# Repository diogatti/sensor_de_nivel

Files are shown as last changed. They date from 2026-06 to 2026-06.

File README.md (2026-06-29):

Este trabalho apresenta uma solução simples e de baixo custo para monitoramento e controle automático do nível de água em um reservatório para aplicações de curto prazo. Visando reduzir desperdícios e promover praticidade e eficiência, foi desenvolvido um sensor resistivo e, de acordo com a medição, exibe-se o valor em um display LCD e controla-se uma bomba de água para regular o volume, utilizando uma Raspberry PI como microcontrolador. Para garantir a precisão, realizou-se a calibração com base em valores conhecidos, o tratamento dos dados na lógica de programação e projetou-se uma estrutura que pudesse ser acoplada ao recipiente para melhorar a estabilidade. O sistema apresentou bons resultados e mostrou-se viável, apesar de apresentar algumas limitações do modelo proposto.

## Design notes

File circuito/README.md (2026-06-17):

# Arquivos realcionados ao circuito do sensor de pcb as simplificações do circuito

## O arquivo PCB_screenshot é uma foto de como sera a organização da pcb
## O arquivo Schmatic_sensor-de-nivel é uma foto de como é o circuito do projeto, ou seja as portas  e os componentes que são utilizados
## OS arquivos  PCB_PCB_sensor-de-nível_2026-06-17 e o SCH_sensor-de-nível_2026-06-17 são os da palaca pcb como png mas .json 
## O arqquivo Gerber_sensor-de-nível_PCB_sensor-de-nível_2026-06-15.zip são os arquivos para impressão da placa

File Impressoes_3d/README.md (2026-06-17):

## Arquivos de impressão 3D

# O arquivo suporte_hastes_separadas foi a impressão final utilizada para segurar as hastes de aço inox
# O arquivo suporte_hastes_cobre foi o arquivo final utilizado para segurar tanto o fio de cobre quanto a solda
# O arquivo suporte_hastes foi a primeira inteção do suporte para segurar as hastes de inox
# Os arquivos suporte_elet e suporte_elet_v2 são os suportes para a placa pcb e e bomba

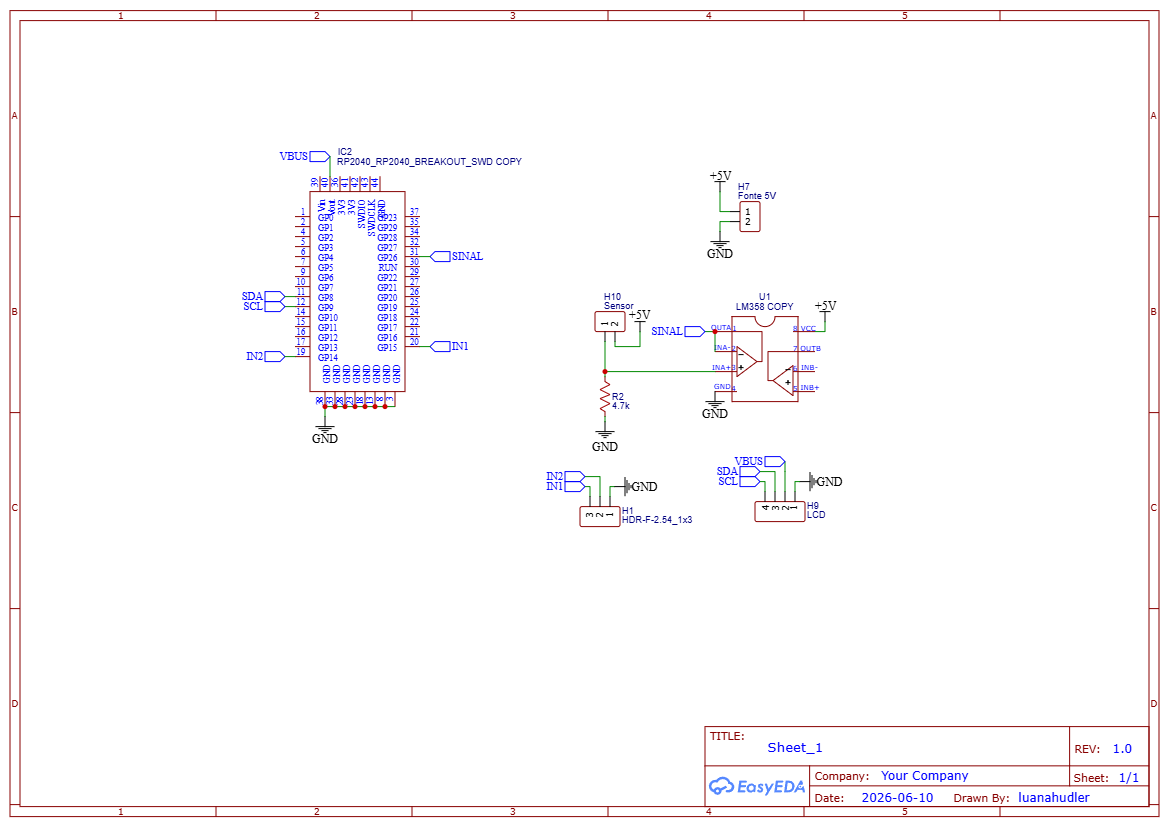
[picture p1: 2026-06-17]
circuito/Schematic_sensor-de-nível.png

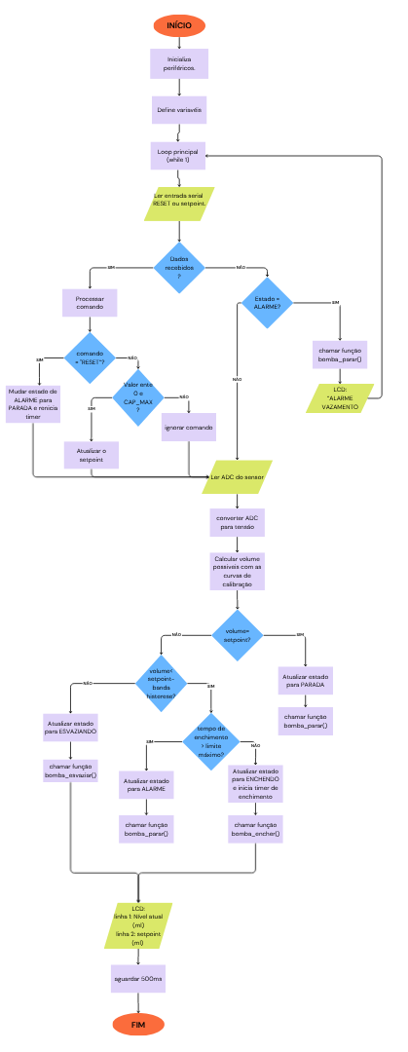
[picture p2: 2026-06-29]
sensor_de_nivel/Fluxograma_código.png

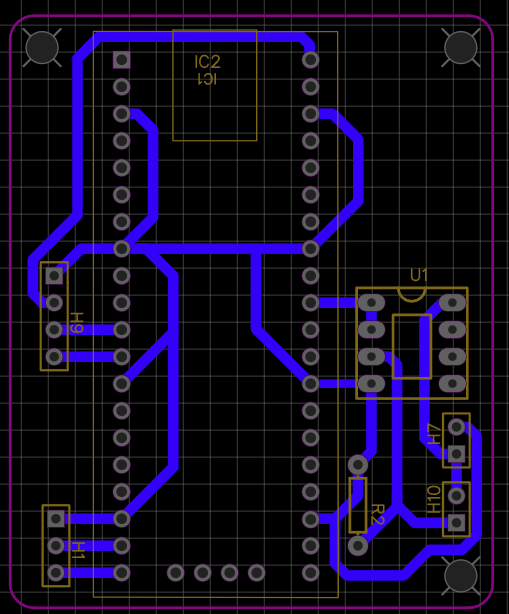
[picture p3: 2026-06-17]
circuito/PCB_screenshot.png

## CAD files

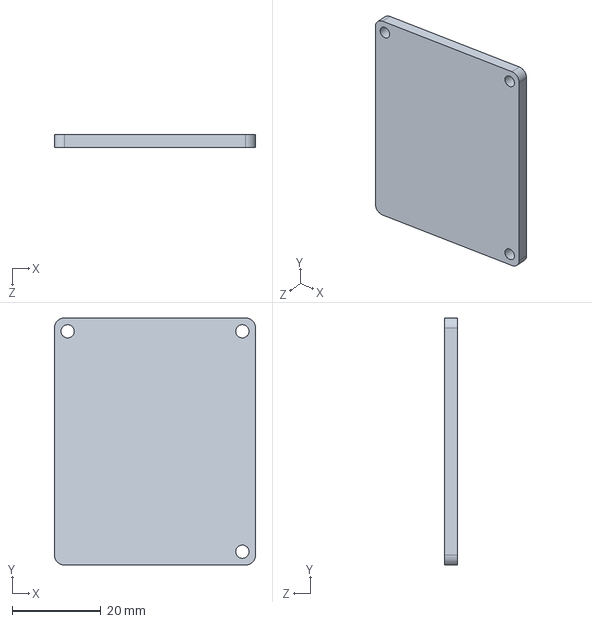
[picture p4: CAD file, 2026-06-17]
circuito/pcb_projeto.SLDPRT
45.4 x 55.7 x 3.00 mm

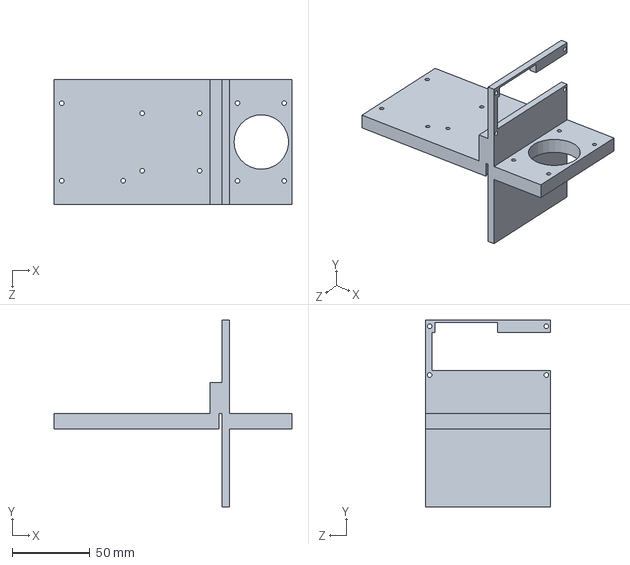
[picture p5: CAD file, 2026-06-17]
Impressoes_3d/suporte_elet_v2.SLDPRT
152.8 x 120.0 x 80.0 mm

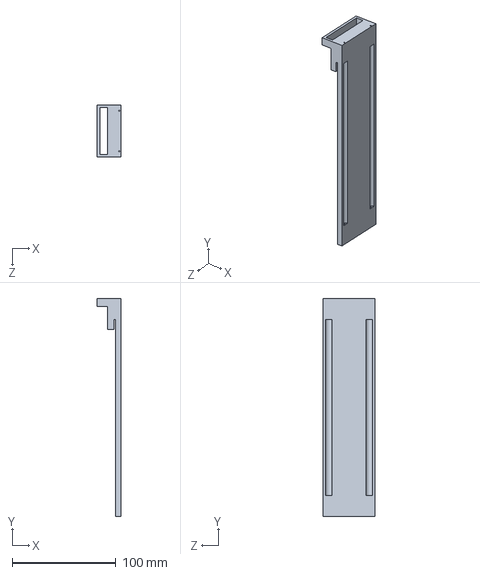
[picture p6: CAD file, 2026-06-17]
Impressoes_3d/suporte_hastes_cobre1.2mm.SLDPRT
22.8 x 210.0 x 50.0 mm

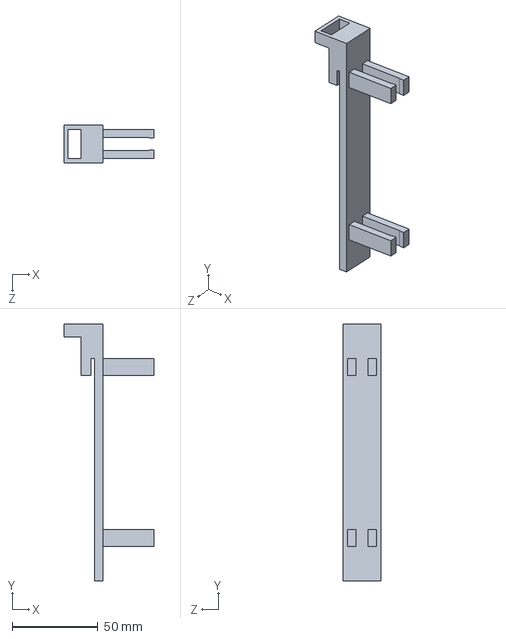
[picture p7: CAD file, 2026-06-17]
Impressoes_3d/suporte_hastes_separadas.SLDPRT
52.8 x 150.0 x 21.9 mm

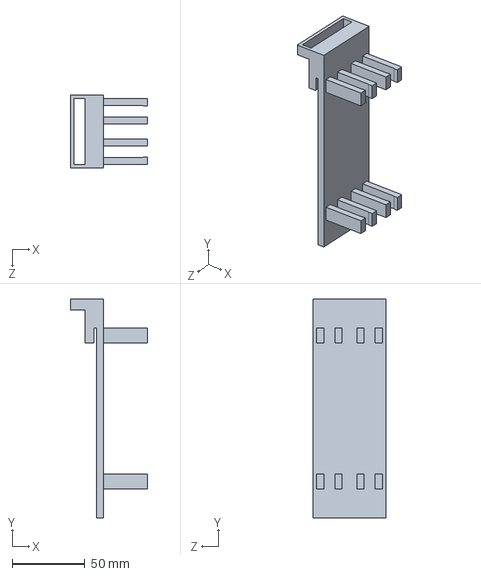
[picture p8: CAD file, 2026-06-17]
Impressoes_3d/suporte_hastes.SLDPRT
52.8 x 150.0 x 50.0 mm

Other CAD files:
Impressoes_3d/suporte_elet.SLDPRT
Impressoes_3d/suporte_elet.STL
Impressoes_3d/suporte_elet_v2.STL
Impressoes_3d/suporte_hastes.STL
Impressoes_3d/suporte_hastes_cobre1.2mm.STL
Impressoes_3d/suporte_hastes_separadas.STL
circuito/pcb_projeto.DXF

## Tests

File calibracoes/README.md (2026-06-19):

# Calibrações realizada nos sensores para compreneder como se pode relacionar as tensões com seus respectivos volumes

## O arquivo calibracao_teste_viabilidade foi realizado na fase inicial do desenvolvimento do projeto para a conpreensão do funcionamento do dos sensor e sua viabilidade, ele foi realizado em dois dias diferentes e sem nenhum suporte impresso, preso somente com fita. Além disso o primeiro teste foi realizado de 100 em 100 ml enquanto oo segundo em 200 e 200 ml.

## O arquivo calibracao_3sens foi a calibração realizada com os 3 possiveis sensores  onde se determinou qual sensor produzia o melhor efeito. O sensor utilizando barra de inox foi posicionado de forma a sobrar 4cm no topo, e ele foi posicionado de forma a ficar cada polo oposto de sim, ou seja a maior distância possivel. O sensor feito com a solda e o sensor feito com o cobre foram posicionados também de forma a ficarem cos os seus polos mais distantes possives   

## O arquivo CALIBRACAO_FINAL foi a calibração final utilizando so a solada e estando conectado no balde somente os aparatos que estariam no projeto final, assim não tendo interferencias dos outros aparatos no volume.

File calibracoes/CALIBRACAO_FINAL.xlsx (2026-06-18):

 | MAX | MIN
200
400
600 | 0.2338 | 0.22242
800 | 0.56249 | 0.5133
1000 | 0.84615 | 0.79169
1200 | 1.09194 | 1.029
1400 | 1.32322 | 1.23
1600 | 1.5012 | 1.4304
1800 | 1.65927 | 1.596
2000 | 1.81158 | 1.7463
2200 | 1.9481 | 1.88974
2400 | 2.0622 | 1.99692
2600 | 2.16132 | 2.13231
2800 | 2.26447 | 2.25238
3000 | 2.36681 | 2.35956
3200 | 2.46029 | 2.43209
3400 | 2.5433 | 2.5159
3600 | 2.6245 | 2.61095
3800 | 2.7608 | 2.66252
4000 | 2.78 | 2.713
4200 | 2.82374 | 2.80117
4400 | 2.90835 | 2.87289
4600 | 2.96799 | 2.94059
4800 | 3.02198 | 2.98088
5000

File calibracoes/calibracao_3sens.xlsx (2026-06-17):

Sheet: 100ML
 | BARRA |  | COBRE |  | SOLDA
100 |  | 100 |  | 100
200 |  | 200 |  | 200
300 |  | 300 |  | 300
400 |  | 400 |  | 400
500 |  | 500 |  | 500
600 |  | 600 |  | 600
700 |  | 700 |  | 700
800 |  | 800 |  | 800
900 |  | 900 |  | 900
1000 |  | 1000 |  | 1000
1100 |  | 1100 |  | 1100
1200 |  | 1200 |  | 1200
1300 |  | 1300 |  | 1300
1400 |  | 1400 |  | 1400
1500 |  | 1500 |  | 1500
1600 |  | 1600 |  | 1600
1700 |  | 1700 |  | 1700
1800 |  | 1800 |  | 1800
1900 |  | 1900 |  | 1900
2000 |  | 2000 |  | 2000
2100 |  | 2100 |  | 2100
2200 |  | 2200 |  | 2200
2300 |  | 2300 |  | 2300
2400 |  | 2400 |  | 2400
2500 |  | 2500 |  | 2500
2600 |  | 2600 |  | 2600
2700 |  | 2700 |  | 2700
2800 |  | 2800 |  | 2800
2900 |  | 2900 |  | 2900
3000 |  | 3000 |  | 3000
3100 |  | 3100 |  | 3100
3200 |  | 3200 |  | 3200
3300 |  | 3300 |  | 3300
3400 |  | 3400 |  | 3400
3500 |  | 3500 |  | 3500
3600 |  | 3600 |  | 3600
3700 |  | 3700 |  | 3700
3800 |  | 3800 |  | 3800
3900 |  | 3900 |  | 3900
4000 |  | 4000 |  | 4000
4100 |  | 4100 |  | 4100
4200 |  | 4200 |  | 4200
4300 |  | 4300 |  | 4300
4400 |  | 4400 |  | 4400
4500 |  | 4500 |  | 4500
4600 |  | 4600 |  | 4600
4700 |  | 4700 |  | 4700
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

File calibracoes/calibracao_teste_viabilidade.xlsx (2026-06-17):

200 | 0.451 | 0.456 |  | 100 | 0 | 0 |  | teste da viabilidade do sensor. Ambas as curvas foram tiradas em dias diferentes com intervalos de medida diferentes , alem de terem sido posicionadas com fita crepe e então dessa forma não permitindo uma consistencia na distancia entre os polos do senor. Ainda assim foi possivel perceber a consistencia do comportamento do sensor
400 | 0.823 | 0.829 |  | 200 | 0 | 0
600 | 1.139 | 1.144 |  | 300 | 0.474 | 0.474
800 | 1.362 | 1.37 |  | 400 | 0.648 | 0.652
1000 | 1.558 | 1.584 |  | 500 | 0.826 | 0.828
1200 | 1.7 | 1.71 |  | 600 | 1.025 | 1.026
1400 | 1.775 | 1.832 | fim da fita | 700 | 1.136 | 1.146
1600 | 1.937 | 1.949 |  | 800 | 1.212 | 1.231
1800 | 2.057 | 2.077 | pega da agua | 900 | 1.326 | 1.334
2000 | 2.156 | 2.191 |  | 1000 | 1.413 | 1.416
2200 | 2.277 | 2.292 |  | 1100 | 1.476 | 1.491
2400 | 2.372 | 2.382 |  | 1200 | 1.59 | 1.6
2600 | 2.432 | 2.463 |  | 1300 | 1.65 | 1.666
2800 | 2.417 | 2.455 |  | 1400 | 1.745 | 1.748
3000 | 2.5 | 2.511 |  | 1500 | 1.8 | 1.826
3200 | 2.566 | 2.574 |  | 1600 | 1.879 | 1.883
3400 | 2.619 | 2.634 |  | 1700 | 1.943 | 1.957
3600 | 2.672 | 2.892 |  | 1800 | 2.022 | 2.026
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

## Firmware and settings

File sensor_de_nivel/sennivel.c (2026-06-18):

#include <stdio.h>
#include <math.h>

#include "pico/stdlib.h"
#include "hardware/adc.h"
#include "hardware/i2c.h"
#include <stdlib.h>
#include <string.h>
// ==========================
// CONFIGURAÇÕES
// ==========================

// deixar o serial monitor o line ending em CR para poder alterar os valores
// CASO A BOMBA FIQUE TENTANDO ENCHER MAIS QUE 30 S O SISTEMA DETECTA VAZAMENTO E PARA O CODIGO, PARA REINICIAR DIGITE RESET
// VALOR DE NIVEL DESEJADO É POSSIVEL ALTERAR DIGITAR SOMENTE O VALOR NO SERIAL MONITOR 
#define ADC_PIN         26      // ADC0
#define ADC_CHANNEL     0

#define IN1             14
#define IN2             15

#define I2C_PORT i2c0
#define SDA_PIN         8
#define SCL_PIN         9

#define LCD_ADDR 0x27

#define LCD_BACKLIGHT 0x08
#define LCD_ENABLE    0x04

#define CAP_MAX  4800.0f // mL
#define CAP_MIN  600.0f//ml

float setpoint = 2600.0f; // nível desejado

#define TEMPO_MAX_ENCHIMENTO_S 300000000000


absolute_time_t inicio_enchimento;

// ==========================
// LCD I2C (PCF8574)
// ==========================


void lcd_send_byte(uint8_t val) {
    i2c_write_blocking(I2C_PORT, LCD_ADDR, &val, 1, false);
}

void lcd_toggle_enable(uint8_t val) {
    sleep_us(1);
    lcd_send_byte(val | LCD_ENABLE);
    sleep_us(1);
    lcd_send_byte(val & ~LCD_ENABLE);
    sleep_us(100);
}

void lcd_send_nibble(uint8_t nibble, uint8_t mode) {
    uint8_t data = (nibble << 4) | mode | LCD_BACKLIGHT;
    lcd_send_byte(data);
    lcd_toggle_enable(data);
}

void lcd_send_cmd(uint8_t cmd) {
    lcd_send_nibble(cmd >> 4, 0);
    lcd_send_nibble(cmd & 0x0F, 0);
}

void lcd_send_char(char c) {
    lcd_send_nibble(c >> 4, 0x01);
    lcd_send_nibble(c & 0x0F, 0x01);
}

void lcd_init() {
    sleep_ms(50);

    lcd_send_nibble(0x03, 0);
    sleep_ms(5);

    lcd_send_nibble(0x03, 0);
    sleep_us(150);

    lcd_send_nibble(0x03, 0);
    lcd_send_nibble(0x02, 0);

    lcd_send_cmd(0x28);
    lcd_send_cmd(0x0C);
    lcd_send_cmd(0x06);
    lcd_send_cmd(0x01);

    sleep_ms(2);
}

void lcd_print(const char *str) {
    while (*str) {
        lcd_send_char(*str++);
    }
}

void lcd_clear()
{
    lcd_send_cmd(0x01);
    sleep_ms(2);
}

void lcd_set_cursor(uint8_t row, uint8_t col)
{
    uint8_t addr = col;

    if(row == 1)
        addr += 0x40;

    lcd_send_cmd(0x80 | addr);
}


// ==========================
// FUNÇÕES DE NÍVEL
// ==========================

float volume_inferior(float tensao)
{
    return exp((tensao + 8.7028f)/1.3781f); //valor solda //exp((tensao + 5.5865f)/1.0064f); //valor barra inox//exp((tensao + 4.3396f)/0.8455f); //valor 1 calibracao
}

float volume_superior(float tensao)
{
    return exp((tensao + 8.5945f)/1.37f); //valor solda //exp((tensao + 4.8861f)/0.9378f); //valor barra inox //exp((tensao + 4.3739f)/0.8518f);//valor 1 calibracao
}

// Histerese usando as duas curvas
float calcular_volume(float tensao)
{
    static float volume_estavel = 0;

    float vinf = volume_inferior(tensao);
    float vsup = volume_superior(tensao);

    float minimo = fmin(vinf,vsup);
    float maximo = fmax(vinf,vsup);

    if(volume_estavel >= minimo &&
       volume_estavel <= maximo)
    {
        return volume_estavel;
    }

    volume_estavel = (vinf + vsup)/2.0f;

    if(volume_estavel < 0)
        volume_estavel = 0;

    if(volume_estavel > CAP_MAX)
        volume_estavel = CAP_MAX;

    return volume_estavel;
}

// ==========================
// CONTROLE DA BOMBA
// ==========================

void bomba_parar()
{
    gpio_put(IN1,0);
    gpio_put(IN2,0);
}

void bomba_encher()
{
    gpio_put(IN1,1);
    gpio_put(IN2,0);
}

void bomba_esvaziar()
{
    gpio_put(IN1,0);
    gpio_put(IN2,1);
}
// ==========================
// CONTROLE COM HISTERESE
// ==========================

typedef enum
{
    PARADA,
    ENCHENDO,
    ESVAZIANDO,
    ALARME
} EstadoBomba;

// banda de histerese
#define BANDA_HISTERESE 200.0f

// tempo mínimo entre mudanças de estado
#define TEMPO_MINIMO_MS 2000

// ==========================
// MAIN
// ==========================

int main()
{
    stdio_init_all();
    sleep_ms(10000);

    printf(" INICIOU");
    // ADC
    adc_init();
    adc_gpio_init(ADC_PIN);
    adc_select_input(ADC_CHANNEL);

    // Ponte H
    gpio_init(IN1);
    gpio_set_dir(IN1, GPIO_OUT);

    gpio_init(IN2);
    gpio_set_dir(IN2, GPIO_OUT);


    bomba_parar();

    // I2C LCD
    i2c_init(I2C_PORT, 100000);

    gpio_set_function(SDA_PIN, GPIO_FUNC_I2C);
    gpio_set_function(SCL_PIN, GPIO_FUNC_I2C);

    gpio_pull_up(SDA_PIN);
    gpio_pull_up(SCL_PIN);

    lcd_init();

    char linha1[17];
    char linha2[17];

    char serial_buffer[20];
    int serial_index = 0;

    EstadoBomba estado = PARADA;

    absolute_time_t ultima_troca = get_absolute_time();

    while(1)
    {
        int c;
        // deixar o serial monitor o line ending em CR para poder alterar os valores
        while((c = getchar_timeout_us(0)) != PICO_ERROR_TIMEOUT)
        {
            //printf("Recebi: %c (%d)\n", c, c);
            if(c == '\n' || c == '\r')
            {
                serial_buffer[serial_index] = '\0';

                //printf("Texto recebido: [%s]\n", serial_buffer);

                if(strcmp(serial_buffer,"RESET") == 0)
                {
                    if(estado == ALARME)
                    {
                        estado = PARADA;

                        ultima_troca = get_absolute_time();

                        printf("ALARME RESETADO\n");
                    }

                    serial_index = 0;

                    continue;
                }

                float novo_setpoint = atof(serial_buffer);

                //printf("Convertido: %.2f\n", novo_setpoint);

                if(novo_setpoint >= 0 && novo_setpoint <= CAP_MAX)
                {
                    setpoint = novo_setpoint;

                    printf("Novo setpoint: %.0f mL\n", setpoint);
                }
                else
                {
                    printf("Valor invalido! Use 0 a %.0f mL\n", CAP_MAX);
                }

                serial_index = 0;
            }
            else
            {
                if(serial_index < sizeof(serial_buffer)-1)
                {
                    serial_buffer[serial_index++] = (char)c;
                    printf("Buffer: %s\n", serial_buffer);
                }
            }
           // printf("Char='%c' ASCII=%d\n", c, c);
        }
        uint16_t adc_raw = adc_read();

        float tensao = ((float)adc_raw * 3.3f) / 4095.0f;

        float volume = calcular_volume(tensao);
    
        // Incrementos de 200 mL
        int volume_display =
            ((int)(volume/200.0f))*200;
        if (volume_display < CAP_MIN)
        {
            volume_display=0;
        }
        // Controle do nível
        bool pode_mudar_estado =
        (
            absolute_time_diff_us(
                ultima_troca,
                get_absolute_time()
            ) > (TEMPO_MINIMO_MS * 1000)
        );

        //printf("Delta = %lld us\n",
          //  absolute_time_diff_us(
          //  ultima_troca,
           // get_absolute_time()));

           if(estado==ALARME)
            {
                bomba_parar();

                lcd_clear();

                lcd_set_cursor(0,0);
                lcd_print("ALARME");

                lcd_set_cursor(1,0);
                lcd_print("VAZAMENTO");

              

                sleep_ms(500);

                continue;
            }

        switch(estado)
        {
            case PARADA:

                if(pode_mudar_estado)
                {
                    if(volume < (setpoint - BANDA_HISTERESE))
                    {
                        estado = ENCHENDO;
                        ultima_troca = get_absolute_time();

                        inicio_enchimento = get_absolute_time();

                        printf("Entrou em ENCHENDO\n");
                    }
                    else if(volume > (setpoint + BANDA_HISTERESE))
                    {
                        estado = ESVAZIANDO;
                        ultima_troca = get_absolute_time();
                    }
                }

                break;

            case ENCHENDO:

                float tempo_enchendo =
                    absolute_time_diff_us(
                        inicio_enchimento,
                        get_absolute_time()
                    ) / 1000000.0f;

                if(tempo_enchendo > TEMPO_MAX_ENCHIMENTO_S)
                {
                    printf("\n");
                    printf("***************\n");
                    printf("ALARME VAZAMENTO\n");
                    printf("***************\n");

                    estado = ALARME;
                    break;
                }

                if(pode_mudar_estado)
                {
                    if(volume >= setpoint)
                    {
                        estado = PARADA;
                        ultima_troca = get_absolute_time();
                    }
                }

                break;

            case ESVAZIANDO:

                if(pode_mudar_estado)
                {
                    if(volume <= setpoint)
                    {
                        estado = PARADA;
                        ultima_troca = get_absolute_time();
                    }
                }

                break;

            case ALARME:
                break;
        }
        switch(estado)
        {
            case PARADA:
                bomba_parar();
                break;

            case ENCHENDO:
                bomba_encher();
                break;

            case ESVAZIANDO:
                bomba_esvaziar();
                break;

            case ALARME:
            bomba_parar();
            break;
        }

        sprintf(linha1,"Nivel:%4dmL",volume_display);
        sprintf(linha2,"SP:%4d",(int)setpoint);

        lcd_clear();

        lcd_set_cursor(0,0);
        lcd_print(linha1);

        lcd_set_cursor(1,0);
        lcd_print(linha2);

        printf(
        "Estado=%d  Vol=%.1f  SP=%.1f  Delta=%.2f S TENSAO=%.5f \n",
        estado,
        volume,
        setpoint,
        absolute_time_diff_us(
            ultima_troca,
            get_absolute_time()
        ) / 1000000.0f,
        tensao
    );

        sleep_ms(500);
    }

    return 0;
}

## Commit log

2026-06-17 codigo do sensor de nivel
2026-06-17 Reorganiza arquivos na pasta sensor-de_nivel
2026-06-17 Adiciona estrutura de diretórios
    [calibracao_3sens.xlsx, calibração_teste_viabilidade.xlsx]
2026-06-17 Adiciona arquivos e readme de cada pasta
    [calibracao_teste_viabilidade.xlsx, pcb_projeto.DXF, pcb_projeto.SLDPRT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]
2026-06-17 Corrige extensao dos arquivos README
    [calibracao_3sens.xlsx, calibracao_teste_viabilidade.xlsx]
2026-06-17 adição dos arquivos de impressão da pcb
2026-06-18 calibração final e determinação de valor minino para visor
    [CALIBRACAO_FINAL.xlsx]
2026-06-29 Adicionamento de fluxograma do código
